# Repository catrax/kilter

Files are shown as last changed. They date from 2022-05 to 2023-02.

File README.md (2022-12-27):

# kilter
A compact multimode eurorack filter with MS-20 style resonance.
Filter core and resonance based on [René Schmitz' MS-20 schematic](https://www.schmitzbits.de/ms20.html).

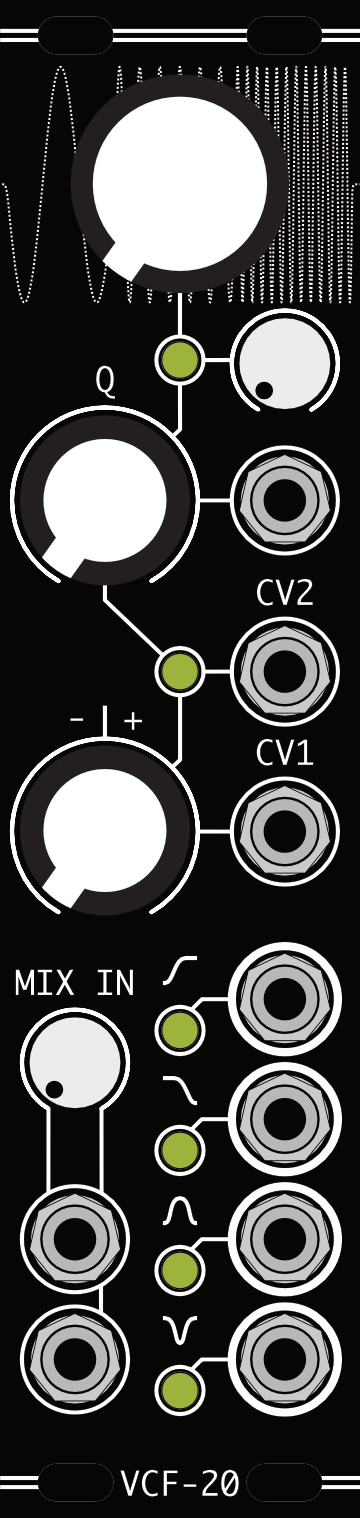
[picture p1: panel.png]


# Features
- Voltage controlled filter with 4 simultaneous outputs:
	- 1-pole high pass
	- 2-pole low pass
	- 2-pole band pass (it's kind of an afterthought and needs to be improved, but it sounds okay)
	- 2-pole notch with adjustable depth (via trimmer on back)
- Two frequency CV inputs, one with an attenuverter
- Voltage controlled resonance with adjustable drive
- Two inputs with linear cross-fade
- 6HP

# Specifications
TODO: HP, power requirements, depth, input/output impedances and voltage ranges

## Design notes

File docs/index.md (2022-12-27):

# (Off) Kilter
Kilter is a 6HP multimode resonant filter based on the Korg MS-20 (yes, yet
another MS-20 clone).

It offers four simultaneous responses, two CV inputs with an attenuverter, two
crossfaded inputs, and voltage controlled resonance with particularly messy
overdrive, all in a compact form factor.
[ TODO ]

If you're building a kit, click [here] for an interactive BOM, and [here] for
calibration instructions. Otherwise, read on for the user manual.

[ TODO: usage manual ]

Specifications:

[ TODO ]

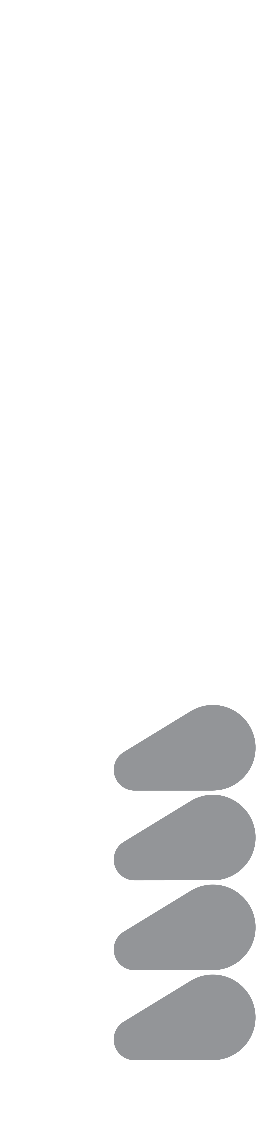
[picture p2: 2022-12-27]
panel/pcb/.svg2shenzhen-cache/images/F.Mask_g251.png

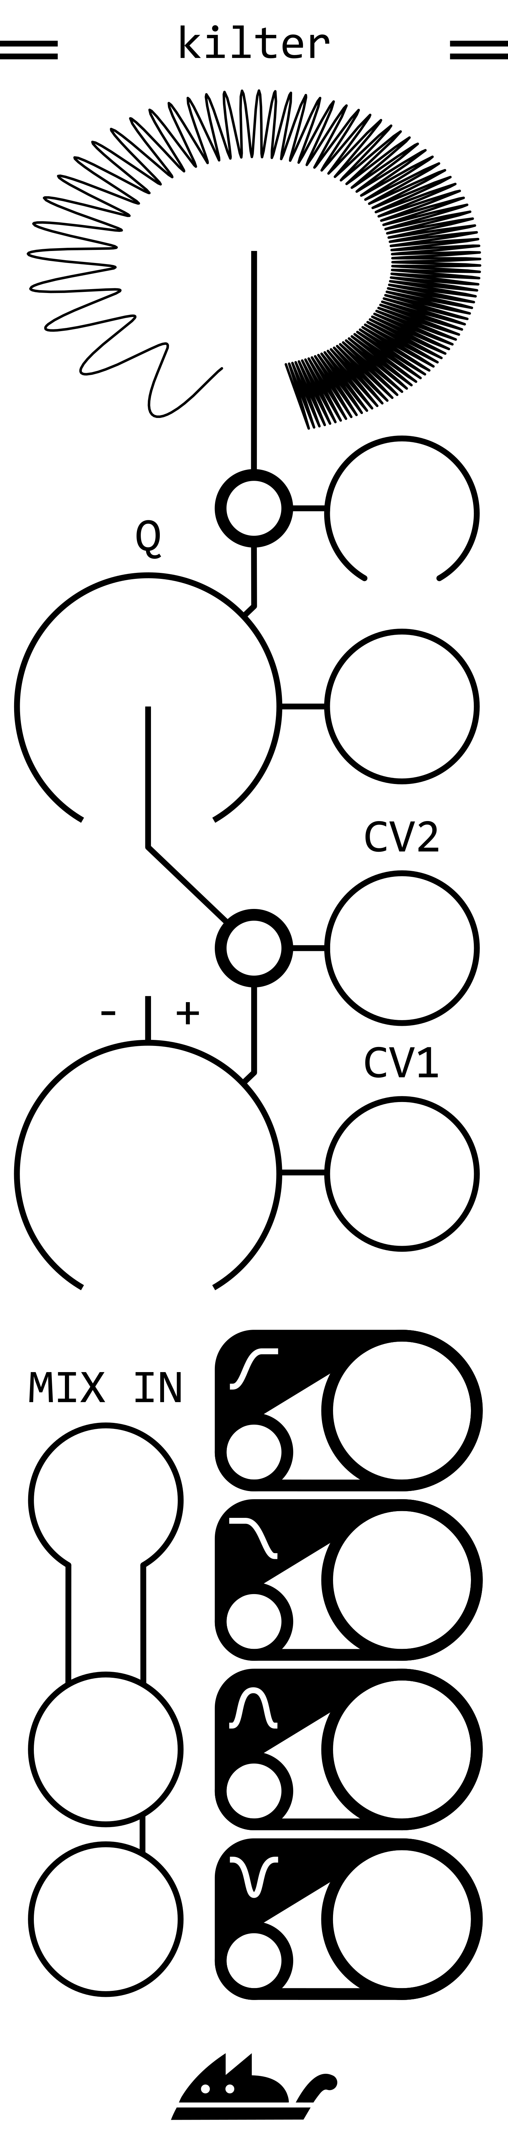
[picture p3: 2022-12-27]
panel/pcb/.svg2shenzhen-cache/images/F.SilkS_g253.png

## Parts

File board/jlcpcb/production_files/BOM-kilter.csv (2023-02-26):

Comment | Designator | Footprint | LCSC
BC857 | Q2 | SOT-363_SC-70-6 | C105887
100nF | C10,C11,C13,C14,C15,C16,C18,C20,C22,C23,C24,C25,C26,C27,C28,C29,C3,C4,C5,C6,C8 | C_0603_1608Metric | C14663
LM4040C5 | U3 | SOT-23 | C156291
1nF | C12,C17,C19,C9 | C_0603_1608Metric | C1588
0.47uF | C7 | C_0603_1608Metric | C1623
LM13700 | U2,U6 | SOIC-16_3.9x9.9mm_P1.27mm | C174050
10uF | C1,C2 | CP_Elec_5x5.3 | C178621
1K | R10,R21,R36,R46,R48,R49,R50,R59,R60,R63,R64 | R_0603_1608Metric | C21190
15K | R1 | R_0603_1608Metric | C22809
1M | R22,R23,R26 | R_0603_1608Metric | C22935
220K | R14,R31 | R_0603_1608Metric | C22961
220R | R12,R13,R24,R29,R3,R33,R34,R4 | R_0603_1608Metric | C22962
4.7K | R19,R37,R7 | R_0603_1608Metric | C23162
470K | R42 | R_0603_1608Metric | C23178
100K | R15,R30,R38,R40,R43,R45,R47,R51,R54,R55,R57,R58 | R_0603_1608Metric | C25803
10K | R11,R16,R17,R18,R20,R25,R27,R28,R32,R35,R39,R5,R52,R53,R56,R6,R61,R62,R8,R9 | R_0603_1608Metric | C25804
47K | R41,R44 | R_0603_1608Metric | C25819
4.7nF | C21 | C_0603_1608Metric | C338071
1.8K | R2 | R_0603_1608Metric | C4177
BC858 | Q1 | SOT-23 | C596216
5K BALANCE | RV6,RV7,RV8 | Potentiometer_Bourns_TC33X_Vertical | C719177
220 | FB1,FB2 | R_0603_1608Metric | C88988
TL072 | U1,U4,U7,U9 | TSSOP-8_4.4x3mm_P0.65mm | C90748
TL074 | U10,U5,U8 | TSSOP-14_4.4x5mm_P0.65mm | C96507
B10K QDRIVE | RV2 | Potentiometer_SongHuei_RD0904N-L25-KQ_Single_Vertical
B10K CV1LVL | RV4 | Potentiometer_Alpha_RD901F-40-00D_Single_Vertical
GREEN | D1 | LED_D3.0mm
CV2 | J2 | PJ301M
QCV | J1 | PJ301M
CV | D2 | LED_D3.0mm_Clear
HP | D3 | LED_D3.0mm_Clear
LP | D4 | LED_D3.0mm_Clear
BP | D5 | LED_D3.0mm_Clear
CV1 | J3 | PJ301M
HP | J4 | PJ301M
LP | J5 | PJ301M
BP | J7 | PJ301M
IN1 | J8 | PJ301M
NOTCH | J9 | PJ301M
POWER | J10 | IDC-Header_2x05_P2.54mm_Vertical
GREEN | D7 | LED_D3.0mm
IN2 | J6 | PJ301M
NOTCH | D6 | LED_D3.0mm_Clear
B10K CUTOFF | RV1 | Potentiometer_Alpha_RD901F-40-00D_Single_Vertical
B10K Q | RV3 | Potentiometer_Alpha_RD901F-40-00D_Single_Vertical
B10K MIX IN | RV5 | Potentiometer_SongHuei_RD0904N-L25-KQ_Single_Vertical

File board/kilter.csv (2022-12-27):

Source: | /home/erin/projects/hardware/vcf-20/board/vcf-20.kicad_sch
Date: | Fri 09 Dec 2022 02:43:01 PM
Tool: | Eeschema (6.0.9)
Generator: | /usr/share/kicad/plugins/bom_csv_grouped_by_value_with_fp.py
Component Count: | 130
Ref | Qnty | Value | Cmp name | Footprint | Description | Vendor
C1, C4, | 2 | 10uF | C_Polarized_Small | Capacitor_SMD:CP_Elec_5x5.3 | Polarized capacitor, small symbol
C2, C3, C5, C6, C7, C8, C9, C10, C11, C15, C16, C18, C19, C20, C21, C22, C23, C24, C25, C28, C29, | 21 | 100nF | C_Small | Capacitor_SMD:C_0603_1608Metric | Unpolarized capacitor, small symbol
C12, C13, C14, | 3 | 1nF | C_Small | Capacitor_SMD:C_0603_1608Metric | Unpolarized capacitor, small symbol
C17, | 1 | 0.47uF | C_Small | Capacitor_SMD:C_0603_1608Metric | Unpolarized capacitor, small symbol
C26, | 1 | 4.7nF | C_Small | Capacitor_SMD:C_0603_1608Metric | Unpolarized capacitor, small symbol
C27, | 1 | 680pF | C_Small | Capacitor_SMD:C_0603_1608Metric | Unpolarized capacitor, small symbol
D1, | 1 | HP | LED_Dual_2pin-Device | LED_THT:LED_D3.0mm_Clear
D2, | 1 | LP | LED_Dual_2pin-Device | LED_THT:LED_D3.0mm_Clear
D3, | 1 | BP | LED_Dual_2pin-Device | LED_THT:LED_D3.0mm_Clear
D4, | 1 | NOTCH | LED_Dual_2pin-Device | LED_THT:LED_D3.0mm_Clear
D5, D6, | 2 | GREEN | LED_Small | LED_THT:LED_D3.0mm | Light emitting diode, small symbol
D7, | 1 | CV | LED_Dual_2pin-Device | LED_THT:LED_D3.0mm_Clear
FB1, FB2, | 2 | 220 | FerriteBead_Small | Resistor_SMD:R_0603_1608Metric | Ferrite bead, small symbol
J1, | 1 | IN1 | PJ-301M-SamacSys_Parts | covertneko_Audio:PJ301M
J2, | 1 | HP | PJ-301M-SamacSys_Parts | covertneko_Audio:PJ301M
J3, | 1 | IN2 | PJ-301M-SamacSys_Parts | covertneko_Audio:PJ301M
J4, | 1 | LP | PJ-301M-SamacSys_Parts | covertneko_Audio:PJ301M
J5, | 1 | BP | PJ-301M-SamacSys_Parts | covertneko_Audio:PJ301M
J6, | 1 | POWER | Conn_02x05_Odd_Even | Connector_IDC:IDC-Header_2x05_P2.54mm_Vertical | Generic connector, double row, 02x05, odd/even pin numbering scheme (row 1 odd numbers, row 2 even numbers), script generated (kicad-library-utils/schlib/autogen/connector/)
J7, | 1 | NOTCH | PJ-301M-SamacSys_Parts | covertneko_Audio:PJ301M
J8, | 1 | QCV | PJ-301M-SamacSys_Parts | covertneko_Audio:PJ301M
J9, | 1 | CV1 | PJ-301M-SamacSys_Parts | covertneko_Audio:PJ301M
J10, | 1 | CV2 | PJ-301M-SamacSys_Parts | covertneko_Audio:PJ301M
Q1, | 1 | BC858 | BC857BS | Package_TO_SOT_SMD:SOT-363_SC-70-6 | 100mA IC, 45V Vce, Dual PNP/PNP Transistors, SOT-363
Q3, | 1 | BC858 | BC858 | Package_TO_SOT_SMD:SOT-23 | 0.1A Ic, 30V Vce, PNP Transistor, SOT-23
R1, R4, R5, R10, R11, R12, R14, R16, R46, R48, R55, | 11 | 1K | R_Small | Resistor_SMD:R_0603_1608Metric | Resistor, small symbol
R2, R3, R6, R7, R8, R9, R44, R49, R51, R53, R56, R60, | 12 | 100K | R_Small | Resistor_SMD:R_0603_1608Metric | Resistor, small symbol
R13, R43, | 2 | 4.7K | R_Small | Resistor_SMD:R_0603_1608Metric | Resistor, small symbol
R15, R17, R18, R19, R20, R21, R22, R23, R24, R25, R26, R27, R28, R35, R37, R38, R39, R40, R45, | 19 | 10K | R_Small | Resistor_SMD:R_0603_1608Metric | Resistor, small symbol
R29, R30, R31, R32, R33, R34, R41, R42, | 8 | 220R | R_Small | Resistor_SMD:R_0603_1608Metric | Resistor, small symbol
R36, | 1 | 1.8K | R_Small | Resistor_SMD:R_0603_1608Metric | Resistor, small symbol
R47, | 1 | 220K | R_Small | Resistor_SMD:R_0603_1608Metric | Resistor, small symbol
R50, | 1 | 470K | R_Small | Resistor_SMD:R_0603_1608Metric | Resistor, small symbol
R52, R59, R61, | 3 | 47K | R_Small | Resistor_SMD:R_0603_1608Metric | Resistor, small symbol
R54, R57, R58, | 3 | 1M | R_Small | Resistor_SMD:R_0603_1608Metric | Resistor, small symbol
RV1, | 1 | 100K BALANCE | R_POT-Device | Potentiometer_SMD:Potentiometer_Bourns_TC33X_Vertical
RV2, | 1 | B10K MIX IN | R_POT-Device | covertneko_General:Potentiometer_SongHuei_RD0904N-L25-KQ_Single_Vertical
RV3, | 1 | 100K NOTCH DEPTH | R_POT-Device | Potentiometer_SMD:Potentiometer_Bourns_TC33X_Vertical
RV4, | 1 | B50K QDRIVE | R_POT-Device | covertneko_General:Potentiometer_SongHuei_RD0904N-L25-KQ_Single_Vertical
RV5, | 1 | 100K QFR | R_POT-Device | Potentiometer_SMD:Potentiometer_Bourns_TC33X_Vertical
RV6, | 1 | B10K CUTOFF | R_POT-Device | covertneko_General:Potentiometer_Alpha_RD901F-40-00D_Single_Vertical
RV7, | 1 | B10K Q | R_POT-Device | covertneko_General:Potentiometer_Alpha_RD901F-40-00D_Single_Vertical
RV8, | 1 | 1K TUNE | R_POT-Device | Potentiometer_SMD:Potentiometer_Bourns_TC33X_Vertical
RV9, | 1 | B10K CV1LVL | R_POT-Device | covertneko_General:Potentiometer_Alpha_RD901F-40-00D_Single_Vertical
U1, U3, U5, | 3 | TL074 | TL074 | Package_SO:TSSOP-14_4.4x5mm_P0.65mm | Quad Low-Noise JFET-Input Operational Amplifiers, DIP-14/SOIC-14
U2, U8, U9, U10, | 4 | TL072 | TL072 | Package_SO:TSSOP-8_4.4x3mm_P0.65mm | Dual Low-Noise JFET-Input Operational Amplifiers, DIP-8/SOIC-8
U4, | 1 | LM4040C5 | LM4040DBZ-5 | Package_TO_SOT_SMD:SOT-23 | 5.000V Precision Micropower Shunt Voltage Reference, SOT-23
U6, U7, | 2 | LM13700 | LM13700-SamacSys_Parts | Package_SO:SOIC-16_3.9x9.9mm_P1.27mm

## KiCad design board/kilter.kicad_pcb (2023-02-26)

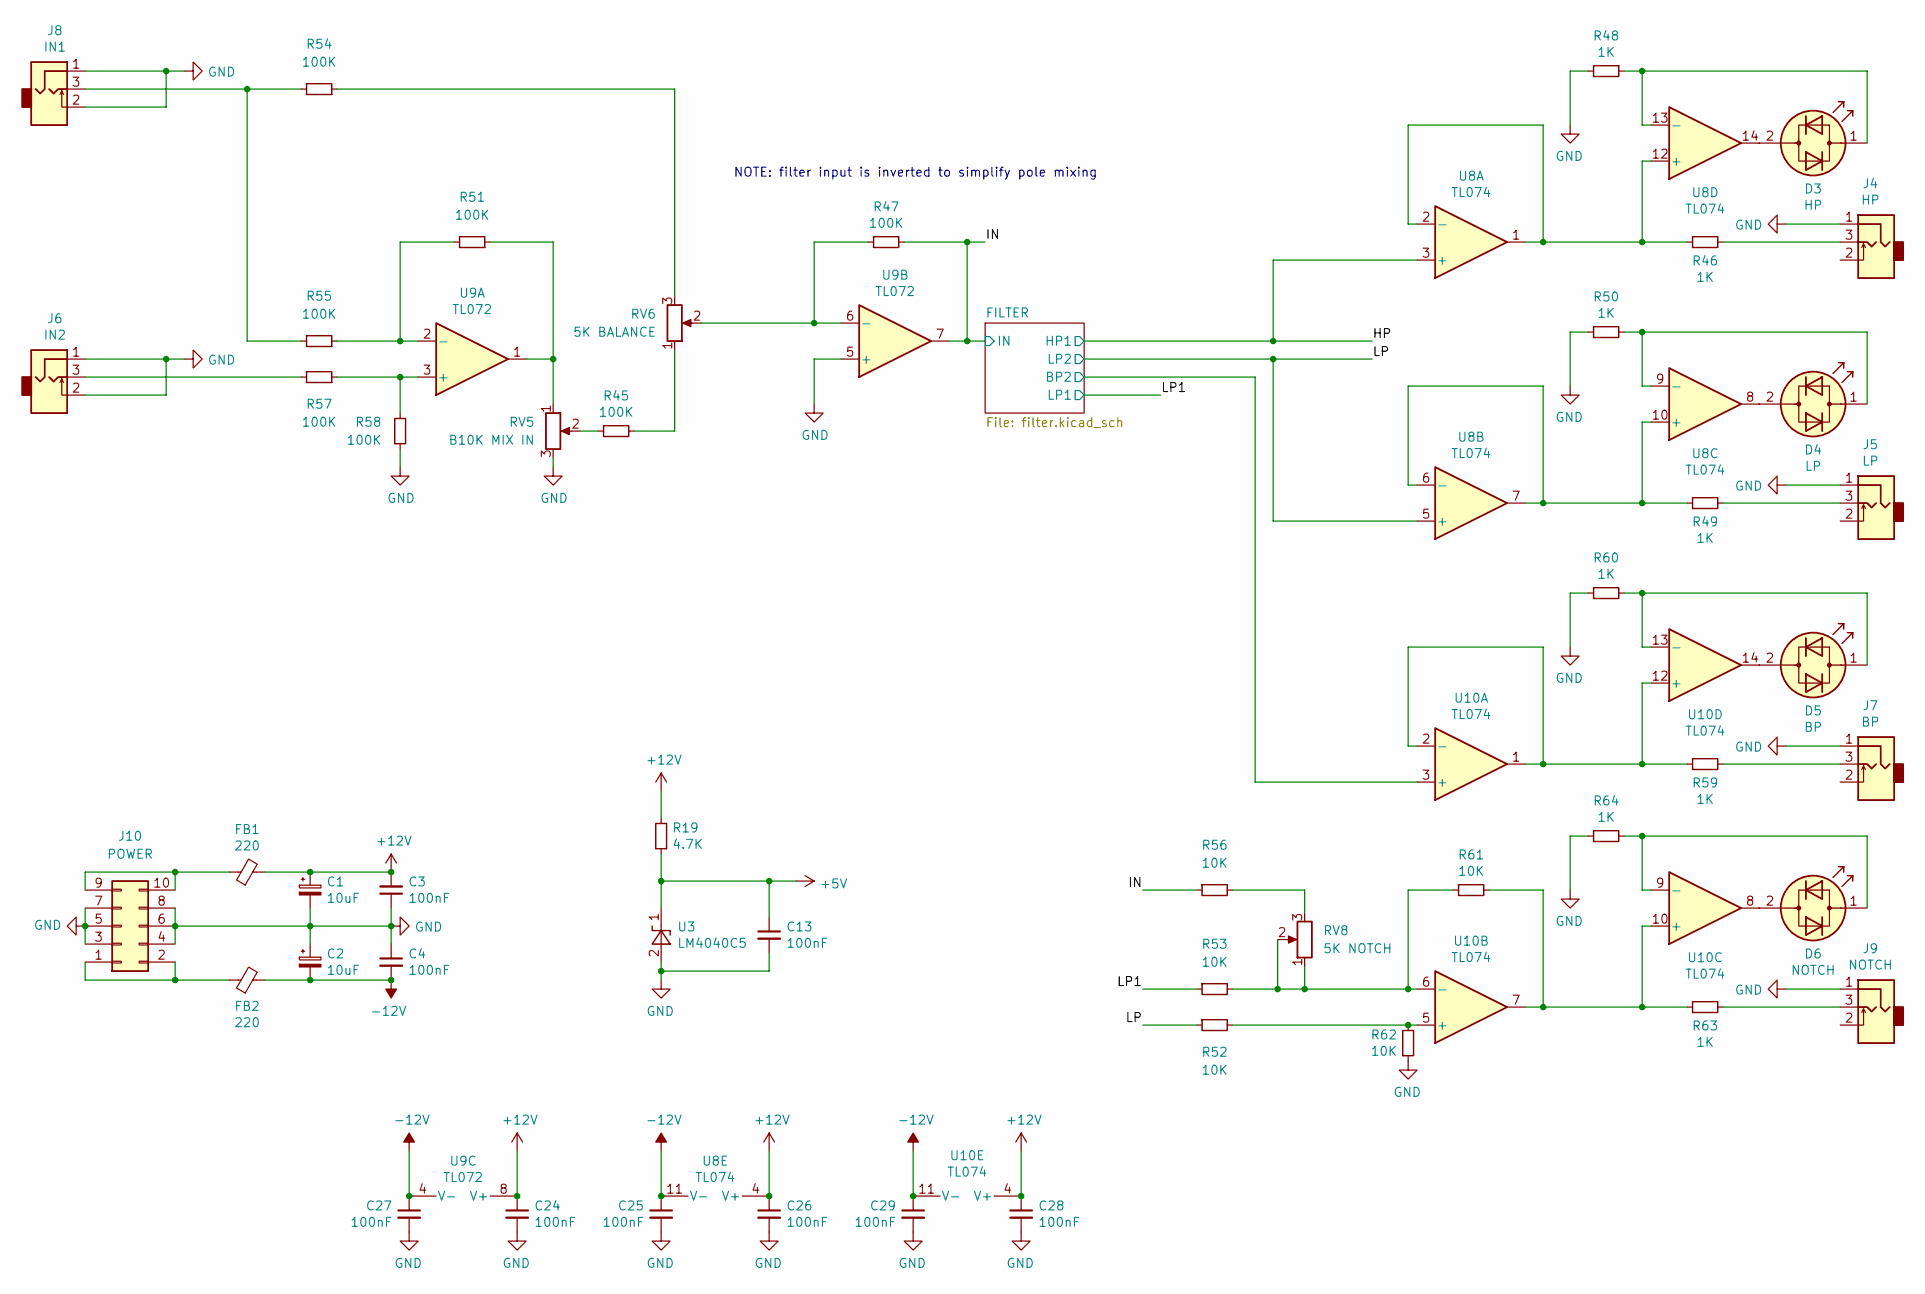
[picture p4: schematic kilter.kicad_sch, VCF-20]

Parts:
C1, C2: 10uF; CP_Elec_5x5.3; LCSC C178621
C3, C4, C13, C24, C25, C26, C27, C28, C29: 100nF; C_0603_1608Metric; LCSC C14663
D3: HP; LED_D3.0mm_Clear
D4: LP; LED_D3.0mm_Clear
D5: BP; LED_D3.0mm_Clear
D6: NOTCH; LED_D3.0mm_Clear
FB1, FB2: 220; R_0603_1608Metric; LCSC C88988
J4: HP; PJ301M
J5: LP; PJ301M
J6: IN2; PJ301M
J7: BP; PJ301M
J8: IN1; PJ301M
J9: NOTCH; PJ301M
J10: POWER; IDC-Header_2x05_P2.54mm_Vertical
R19: 4.7K; R_0603_1608Metric; LCSC C23162
R45, R47, R51, R54, R55, R57, R58: 100K; R_0603_1608Metric; LCSC C25803
R46, R48, R49, R50, R59, R60, R63, R64: 1K; R_0603_1608Metric; LCSC C21190
R52, R53, R56, R61, R62: 10K; R_0603_1608Metric; LCSC C25804
RV5: B10K MIX IN; Potentiometer_SongHuei_RD0904N-L25-KQ_Single_Vertical
RV6: 5K BALANCE; Potentiometer_Bourns_TC33X_Vertical; LCSC C719177
RV8: 5K NOTCH; Potentiometer_Bourns_TC33X_Vertical; LCSC C719177
U3: LM4040C5; SOT-23; LCSC C156291
U8, U10: TL074; TSSOP-14_4.4x5mm_P0.65mm; LCSC C96507
U9: TL072; TSSOP-8_4.4x3mm_P0.65mm; LCSC C90748

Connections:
+5V: C13.1, R19.1, U3.1 (K); also elsewhere on the board
+12V: C1.1, C3.2, C24.1, C26.1, C28.1, FB1.2, R19.2, U8.4 (V+), U9.8 (V+), U10.4 (V+); also elsewhere on the board
-12V: C2.2, C4.2, C25.1, C27.1, C29.1, FB2.2, U8.11 (V-), U9.4 (V-), U10.11 (V-); also elsewhere on the board
/FILTER/BP2: U10.3 (+); also elsewhere on the board
/HP: U8.3 (+); also elsewhere on the board
/IN: R47.2, R56.1, U9.7; also elsewhere on the board
/LP: R52.1, U8.5 (+); also elsewhere on the board
/LP1: R53.1; also elsewhere on the board
GND: C1.2, C2.1, C3.1, C4.1, C13.2, C24.2, C25.2, C26.2, C27.2, C28.2, C29.2, J4.1, J5.1, J6.1, J6.2, J7.1, J8.1, J8.2, J9.1, J10.3, J10.4, J10.5, J10.6, J10.7, J10.8, R48.2, R50.1, R58.1, R60.1, R62.1, R64.1, RV5.3, U3.2 (A), U9.5 (+); also elsewhere on the board
unnamed: D3.1 (KA), R48.1, U8.13 (-)
unnamed: D3.2 (AK), U8.14
unnamed: D4.1 (KA), R50.2, U8.9 (-)
unnamed: D4.2 (AK), U8.8
unnamed: D5.1 (KA), R60.2, U10.13 (-)
unnamed: D5.2 (AK), U10.14
unnamed: D6.1 (KA), R64.2, U10.9 (-)
unnamed: D6.2 (AK), U10.8
unnamed: FB1.1, J10.9, J10.10
unnamed: FB2.1, J10.1, J10.2
unnamed: J8.3, R54.2, R55.2
unnamed: J4.3, R46.2
unnamed: J6.3, R57.2
unnamed: J5.3, R49.2
unnamed: J7.3, R59.2
unnamed: J9.3, R63.2
unnamed: R51.1, RV5.1, U9.1
unnamed: R51.2, R55.1, U9.2 (-)
unnamed: R47.1, RV6.2, U9.6 (-)
unnamed: R46.1, U8.1, U8.2 (-), U8.12 (+)
unnamed: R57.1, R58.2, U9.3 (+)
unnamed: R45.1, RV5.2
unnamed: R45.2, RV6.1
unnamed: R49.1, U8.6 (-), U8.7, U8.10 (+)
unnamed: R59.1, U10.1, U10.2 (-), U10.12 (+)
unnamed: R53.2, R61.1, RV8.1, RV8.2, U10.6 (-)
unnamed: R61.2, R63.1, U10.7, U10.10 (+)
unnamed: R52.2, R62.2, U10.5 (+)
unnamed: R54.1, RV6.3
unnamed: R56.2, RV8.3

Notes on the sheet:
NOTE: filter input is inverted to simplify pole mixing

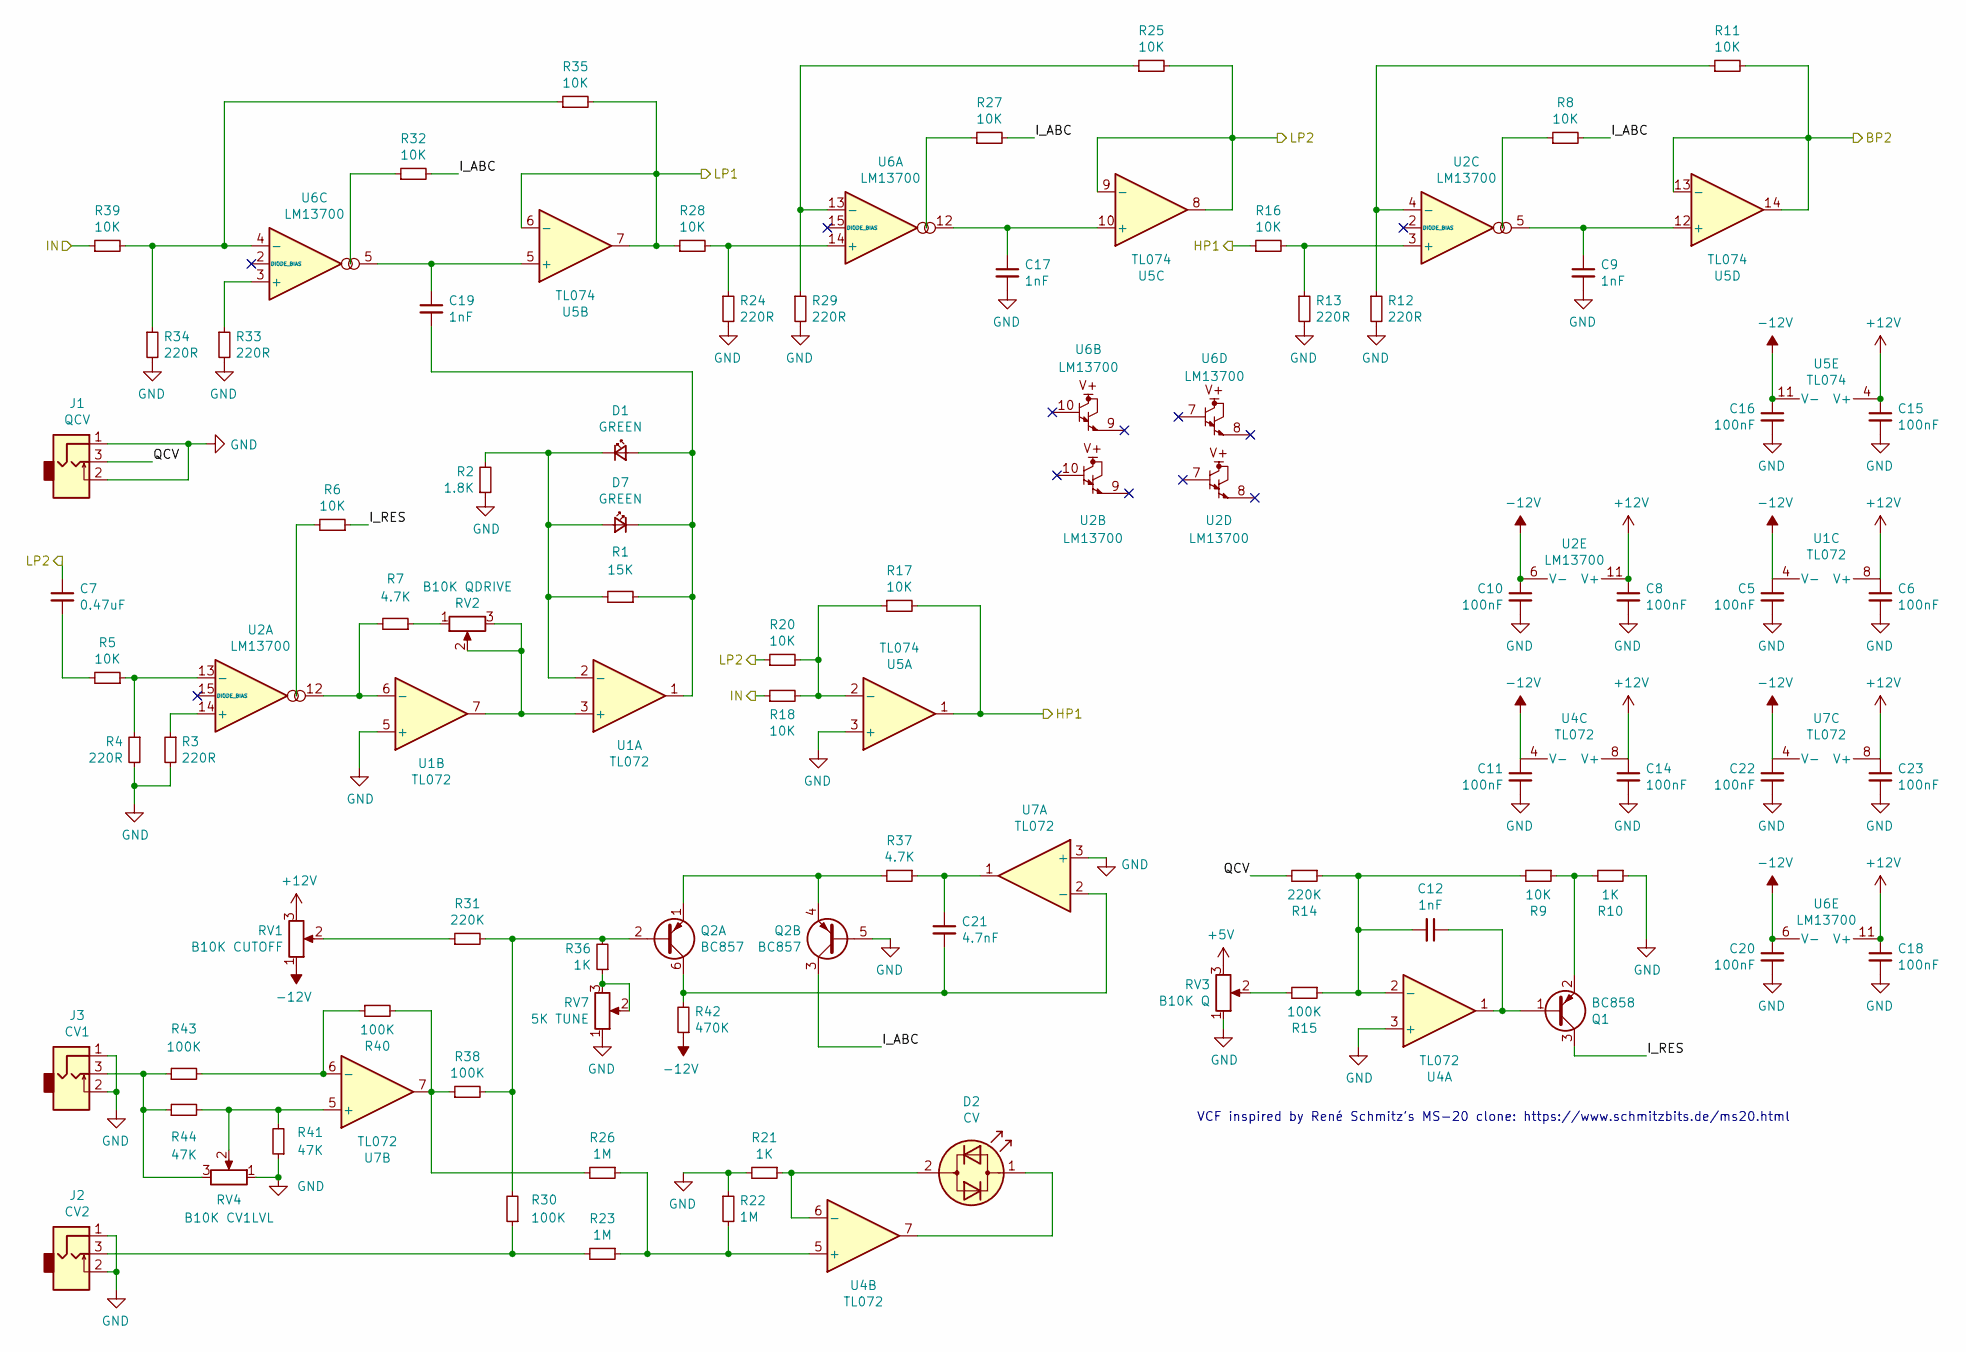
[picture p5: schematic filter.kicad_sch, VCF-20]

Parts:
C5, C6, C8, C10, C11, C14, C15, C16, C18, C20, C22, C23: 100nF; C_0603_1608Metric; LCSC C14663
C7: 0.47uF; C_0603_1608Metric; LCSC C1623
C9, C12, C17, C19: 1nF; C_0603_1608Metric; LCSC C1588
C21: 4.7nF; C_0603_1608Metric; LCSC C338071
D1, D7: GREEN; LED_D3.0mm
D2: CV; LED_D3.0mm_Clear
J1: QCV; PJ301M
J2: CV2; PJ301M
J3: CV1; PJ301M
Q1: BC858; SOT-23; LCSC C596216
Q2: BC857; SOT-363_SC-70-6; LCSC C105887
R1: 15K; R_0603_1608Metric; LCSC C22809
R2: 1.8K; R_0603_1608Metric; LCSC C4177
R3, R4, R12, R13, R24, R29, R33, R34: 220R; R_0603_1608Metric; LCSC C22962
R5, R6, R8, R9, R11, R16, R17, R18, R20, R25, R27, R28, R32, R35, R39: 10K; R_0603_1608Metric; LCSC C25804
R7, R37: 4.7K; R_0603_1608Metric; LCSC C23162
R10, R21, R36: 1K; R_0603_1608Metric; LCSC C21190
R14, R31: 220K; R_0603_1608Metric; LCSC C22961
R15, R30, R38, R40, R43: 100K; R_0603_1608Metric; LCSC C25803
R22, R23, R26: 1M; R_0603_1608Metric; LCSC C22935
R41, R44: 47K; R_0603_1608Metric; LCSC C25819
R42: 470K; R_0603_1608Metric; LCSC C23178
RV1: B10K CUTOFF; Potentiometer_Alpha_RD901F-40-00D_Single_Vertical
RV2: B10K QDRIVE; Potentiometer_SongHuei_RD0904N-L25-KQ_Single_Vertical
RV3: B10K Q; Potentiometer_Alpha_RD901F-40-00D_Single_Vertical
RV4: B10K CV1LVL; Potentiometer_Alpha_RD901F-40-00D_Single_Vertical
RV7: 5K TUNE; Potentiometer_Bourns_TC33X_Vertical; LCSC C719177
U1, U4, U7: TL072; TSSOP-8_4.4x3mm_P0.65mm; LCSC C90748
U2, U6: LM13700; SOIC-16_3.9x9.9mm_P1.27mm; LCSC C174050
U5: TL074; TSSOP-14_4.4x5mm_P0.65mm; LCSC C96507

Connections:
+5V: RV3.3; also elsewhere on the board
+12V: C6.1, C8.1, C14.1, C15.1, C18.1, C23.1, RV1.3, U1.8 (V+), U2.11 (V+), U4.8 (V+), U5.4 (V+), U6.11 (V+), U7.8 (V+); also elsewhere on the board
-12V: C5.1, C10.1, C11.1, C16.1, C20.1, C22.1, R42.1, RV1.1, U1.4 (V-), U2.6 (V-), U4.4 (V-), U5.11 (V-), U6.6 (V-), U7.4 (V-); also elsewhere on the board
/FILTER/BP2: R11.2, U5.13 (-), U5.14; also elsewhere on the board
/FILTER/I_ABC: Q2.3 (C2), R8.2, R27.2, R32.2
/FILTER/I_RES: Q1.3 (C), R6.1
/FILTER/QCV: J1.3, R14.2
/HP: R16.1, R17.2, U5.1; also elsewhere on the board
/IN: R18.1, R39.1; also elsewhere on the board
/LP: C7.1, R20.1, R25.2, U5.8, U5.9 (-); also elsewhere on the board
/LP1: R28.1, R35.2, U5.6 (-), U5.7; also elsewhere on the board
GND: C5.2, C6.2, C8.2, C9.2, C10.2, C11.2, C14.2, C15.2, C16.2, C17.2, C18.2, C20.2, C22.2, C23.2, J1.1, J1.2, J2.1, J2.2, J3.1, J3.2, Q2.5 (B2), R2.1, R3.2, R4.2, R10.1, R12.2, R13.2, R21.2, R22.1, R24.2, R29.2, R33.2, R34.2, R41.1, RV3.1, RV4.1, RV7.1, U1.5 (+), U4.3 (+), U5.3 (+), U7.3 (+); also elsewhere on the board
unnamed: C17.1, U5.10 (+), U6.12
unnamed: C9.1, U2.5, U5.12 (+)
unnamed: C19.1, U5.5 (+), U6.5
unnamed: C19.2, D1.2 (A), D7.1 (K), R1.1, U1.1
unnamed: C7.2, R5.2
unnamed: C21.1, R37.1, U7.1
unnamed: C21.2, Q2.6 (C1), R42.2, U7.2 (-)
unnamed: C12.1, Q1.1 (B), U4.1
unnamed: C12.2, R9.2, R14.1, R15.1, U4.2 (-)
unnamed: D1.1 (K), D7.2 (A), R1.2, R2.2, U1.2 (-)
unnamed: D2.1 (KA), U4.7
unnamed: D2.2 (AK), R21.1, U4.6 (-)
unnamed: J3.3, R43.1, R44.1, RV4.3
unnamed: J2.3, R23.2, R30.1
unnamed: Q2.1 (E1), Q2.4 (E2), R37.2
unnamed: Q2.2 (B1), R30.2, R31.2, R36.2, R38.2
unnamed: Q1.2 (E), R9.1, R10.2
unnamed: R25.1, R29.1, U6.13 (-)
unnamed: R11.1, R12.1, U2.4 (-)
unnamed: R34.1, R35.1, R39.2, U6.4 (-)
unnamed: R27.1, U6.16
unnamed: R8.1, U2.1
unnamed: R32.1, U6.1
unnamed: R24.1, R28.2, U6.14 (+)
unnamed: R13.1, R16.2, U2.3 (+)
unnamed: R33.1, U6.3 (+)
unnamed: R17.1, R18.2, R20.2, U5.2 (-)
unnamed: R6.2, U2.16
unnamed: R4.1, R5.1, U2.13 (-)
unnamed: R3.1, U2.14 (+)
unnamed: R31.1, RV1.2
unnamed: R36.1, RV7.2, RV7.3
unnamed: R15.2, RV3.2
unnamed: R26.2, R38.1, R40.2, U7.7
unnamed: R41.2, R44.2, RV4.2, U7.5 (+)
unnamed: R40.1, R43.2, U7.6 (-)
unnamed: R22.2, R23.1, R26.1, U4.5 (+)
unnamed: R7.1, RV2.1
unnamed: R7.2, U1.6 (-), U2.12
unnamed: RV2.2, RV2.3, U1.3 (+), U1.7

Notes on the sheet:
VCF inspired by René Schmitz's MS-20 clone: https://www.schmitzbits.de/ms20.html

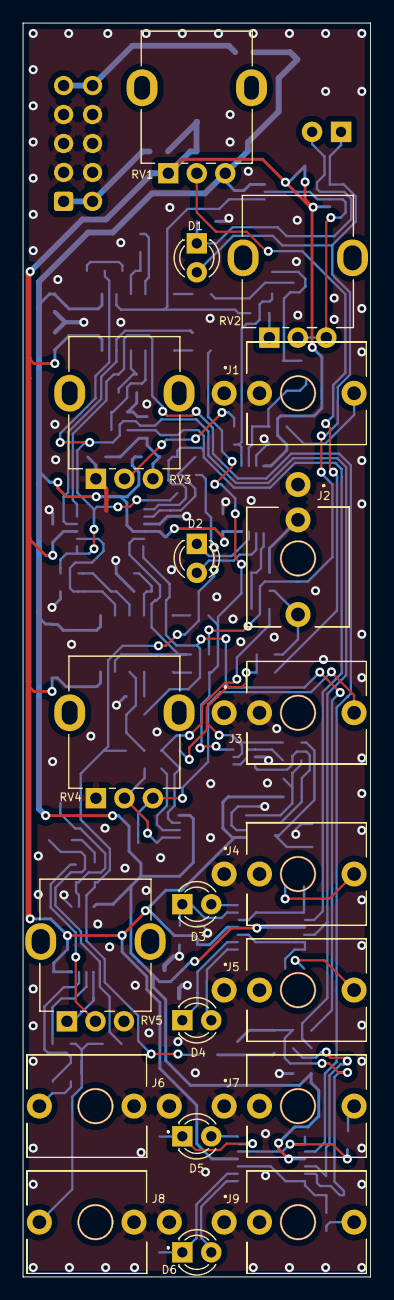
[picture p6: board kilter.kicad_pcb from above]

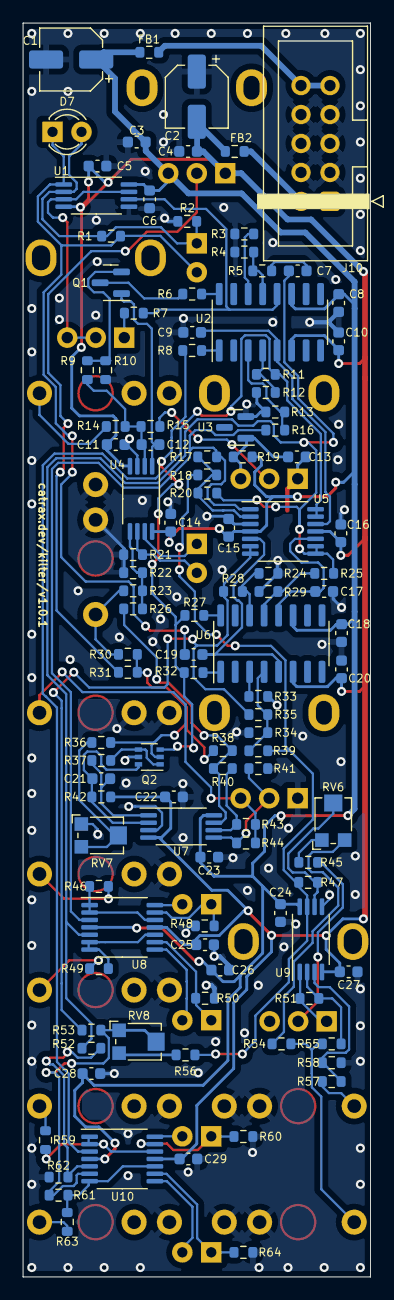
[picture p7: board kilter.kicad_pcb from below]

Board: 2 copper layers, 30.5 x 110.0 mm, 132 parts (112 on the bottom side), 82 nets.

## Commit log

2020-08-22 Initial commit of existing v0.1 design
    [bom.csv, filter.sch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]
2020-09-01 Update schematic with resonance and crossfader fixes
    [filter.sch, vcf-20.sch]
2020-11-08 Redesign filter core and revise board layout
    [bom.csv, filter.sch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]
2022-05-18 Add panel, plus some minor fixes to crossfade and resonance drive
    [filter.sch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]
2022-12-27 fix crossfade and notch; improve attenuverter
    [SDS00001_bode.csv, filter.kicad_sch, filter.sch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]
2022-12-27 rename project
    [kilter.csv, kilter.kicad_pcb, kilter.kicad_sch]
2022-12-27 Fix mounting holes for tall trimmer pots
    [kilter.kicad_pcb]
2022-12-27 Fix reference designator rotations
    [kilter.kicad_pcb]
2022-12-29 Update panel and add jlcpcb assembly files
    [BOM-kilter.csv, filter.kicad_sch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]
2023-02-25 fix resonance gain and simplify module calibration
    [filter.kicad_sch, kilter.kicad_pcb, kilter.kicad_sch]
2023-02-26 fix back silkscreen and update production files
    [BOM-kilter.csv, filter.kicad_sch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]
